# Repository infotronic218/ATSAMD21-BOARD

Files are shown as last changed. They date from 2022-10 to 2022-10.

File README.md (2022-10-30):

# ATSAMD21-BOARD  designed Within Kicad 6
The aim of this project is to design a simple development board for ARM Based MCU line of Microchip for quick use and experimentation of the MCU interfaces. Severals sensors and modules are connected to the MCU interfaces for quick code implementation and testing.
## Used main components in the design 
+ Microchip MCU  ATSAMD21G17D-A
+ UART/USB Transceiver for debugging
+ SW Debug interface over JLINK
+ Bluetooth module (DA14531MOD) over UART 
+ LORA Module (RFM95W) over SPI
+ LED Driver (IS31FL3737) over I2C
+ Lion Battery charger (MCP73831-2-OT)
+ FLASH Memory (16Mbits) Over SPI
+ Temperature and humidity sensor (SHT40) over I2C
+ Digital LED (IN-PI554FCH)
+ GPIO exposed pins 
## PCB LAYOUT VIEWS 
 
1. TOP LAYER LAYOUT 

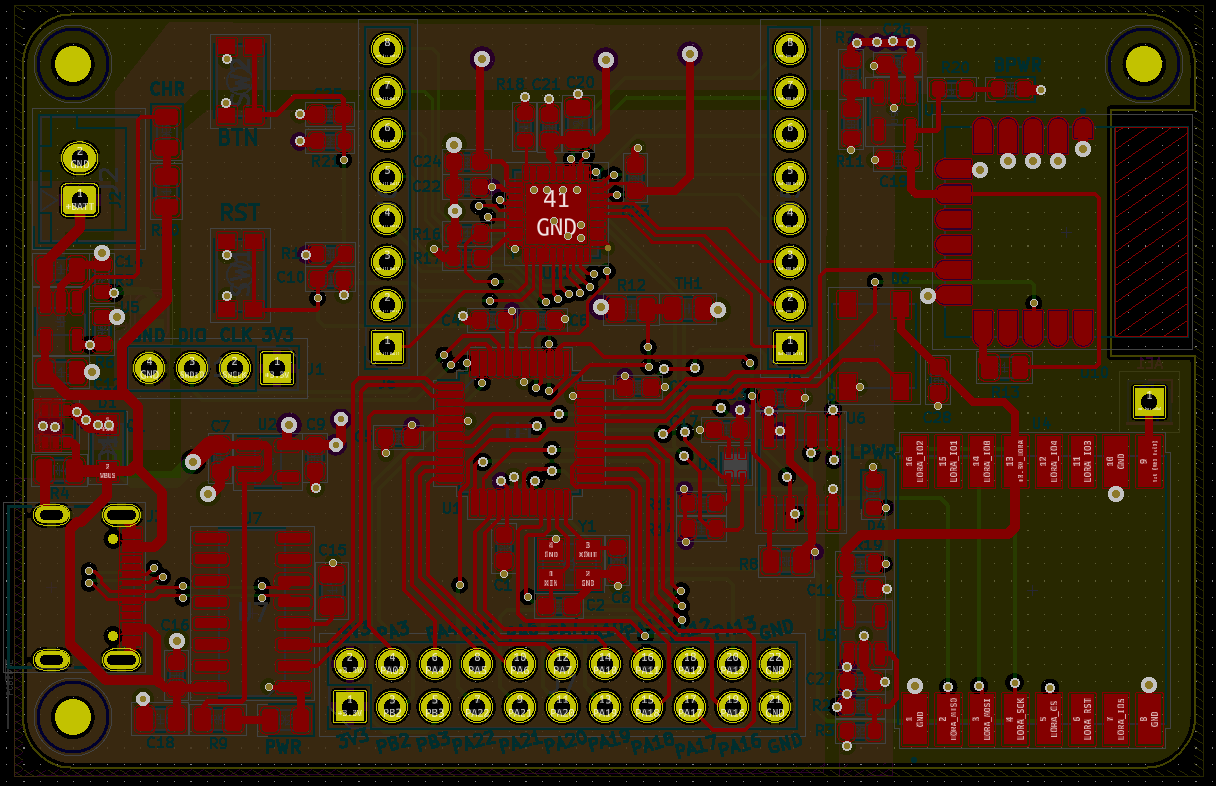
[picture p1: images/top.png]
Top layer


2. BOTTOM LAYER LAYOUT

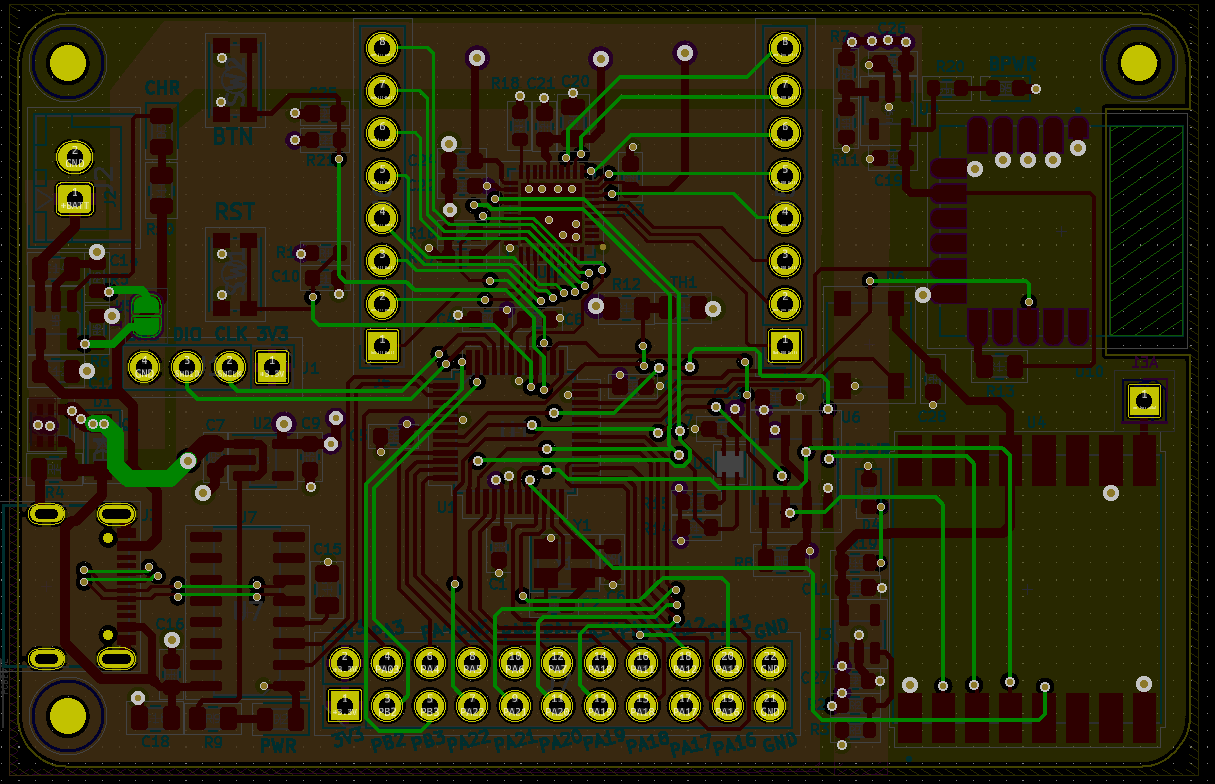
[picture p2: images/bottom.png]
Bottom layer


3. 3D VIEW

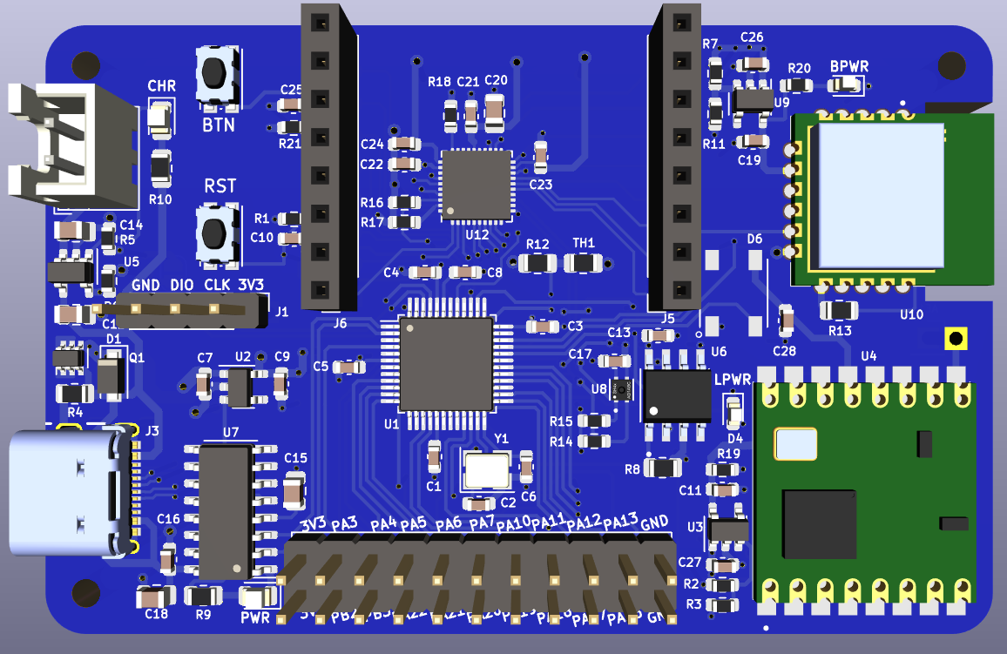
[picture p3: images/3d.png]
3D View


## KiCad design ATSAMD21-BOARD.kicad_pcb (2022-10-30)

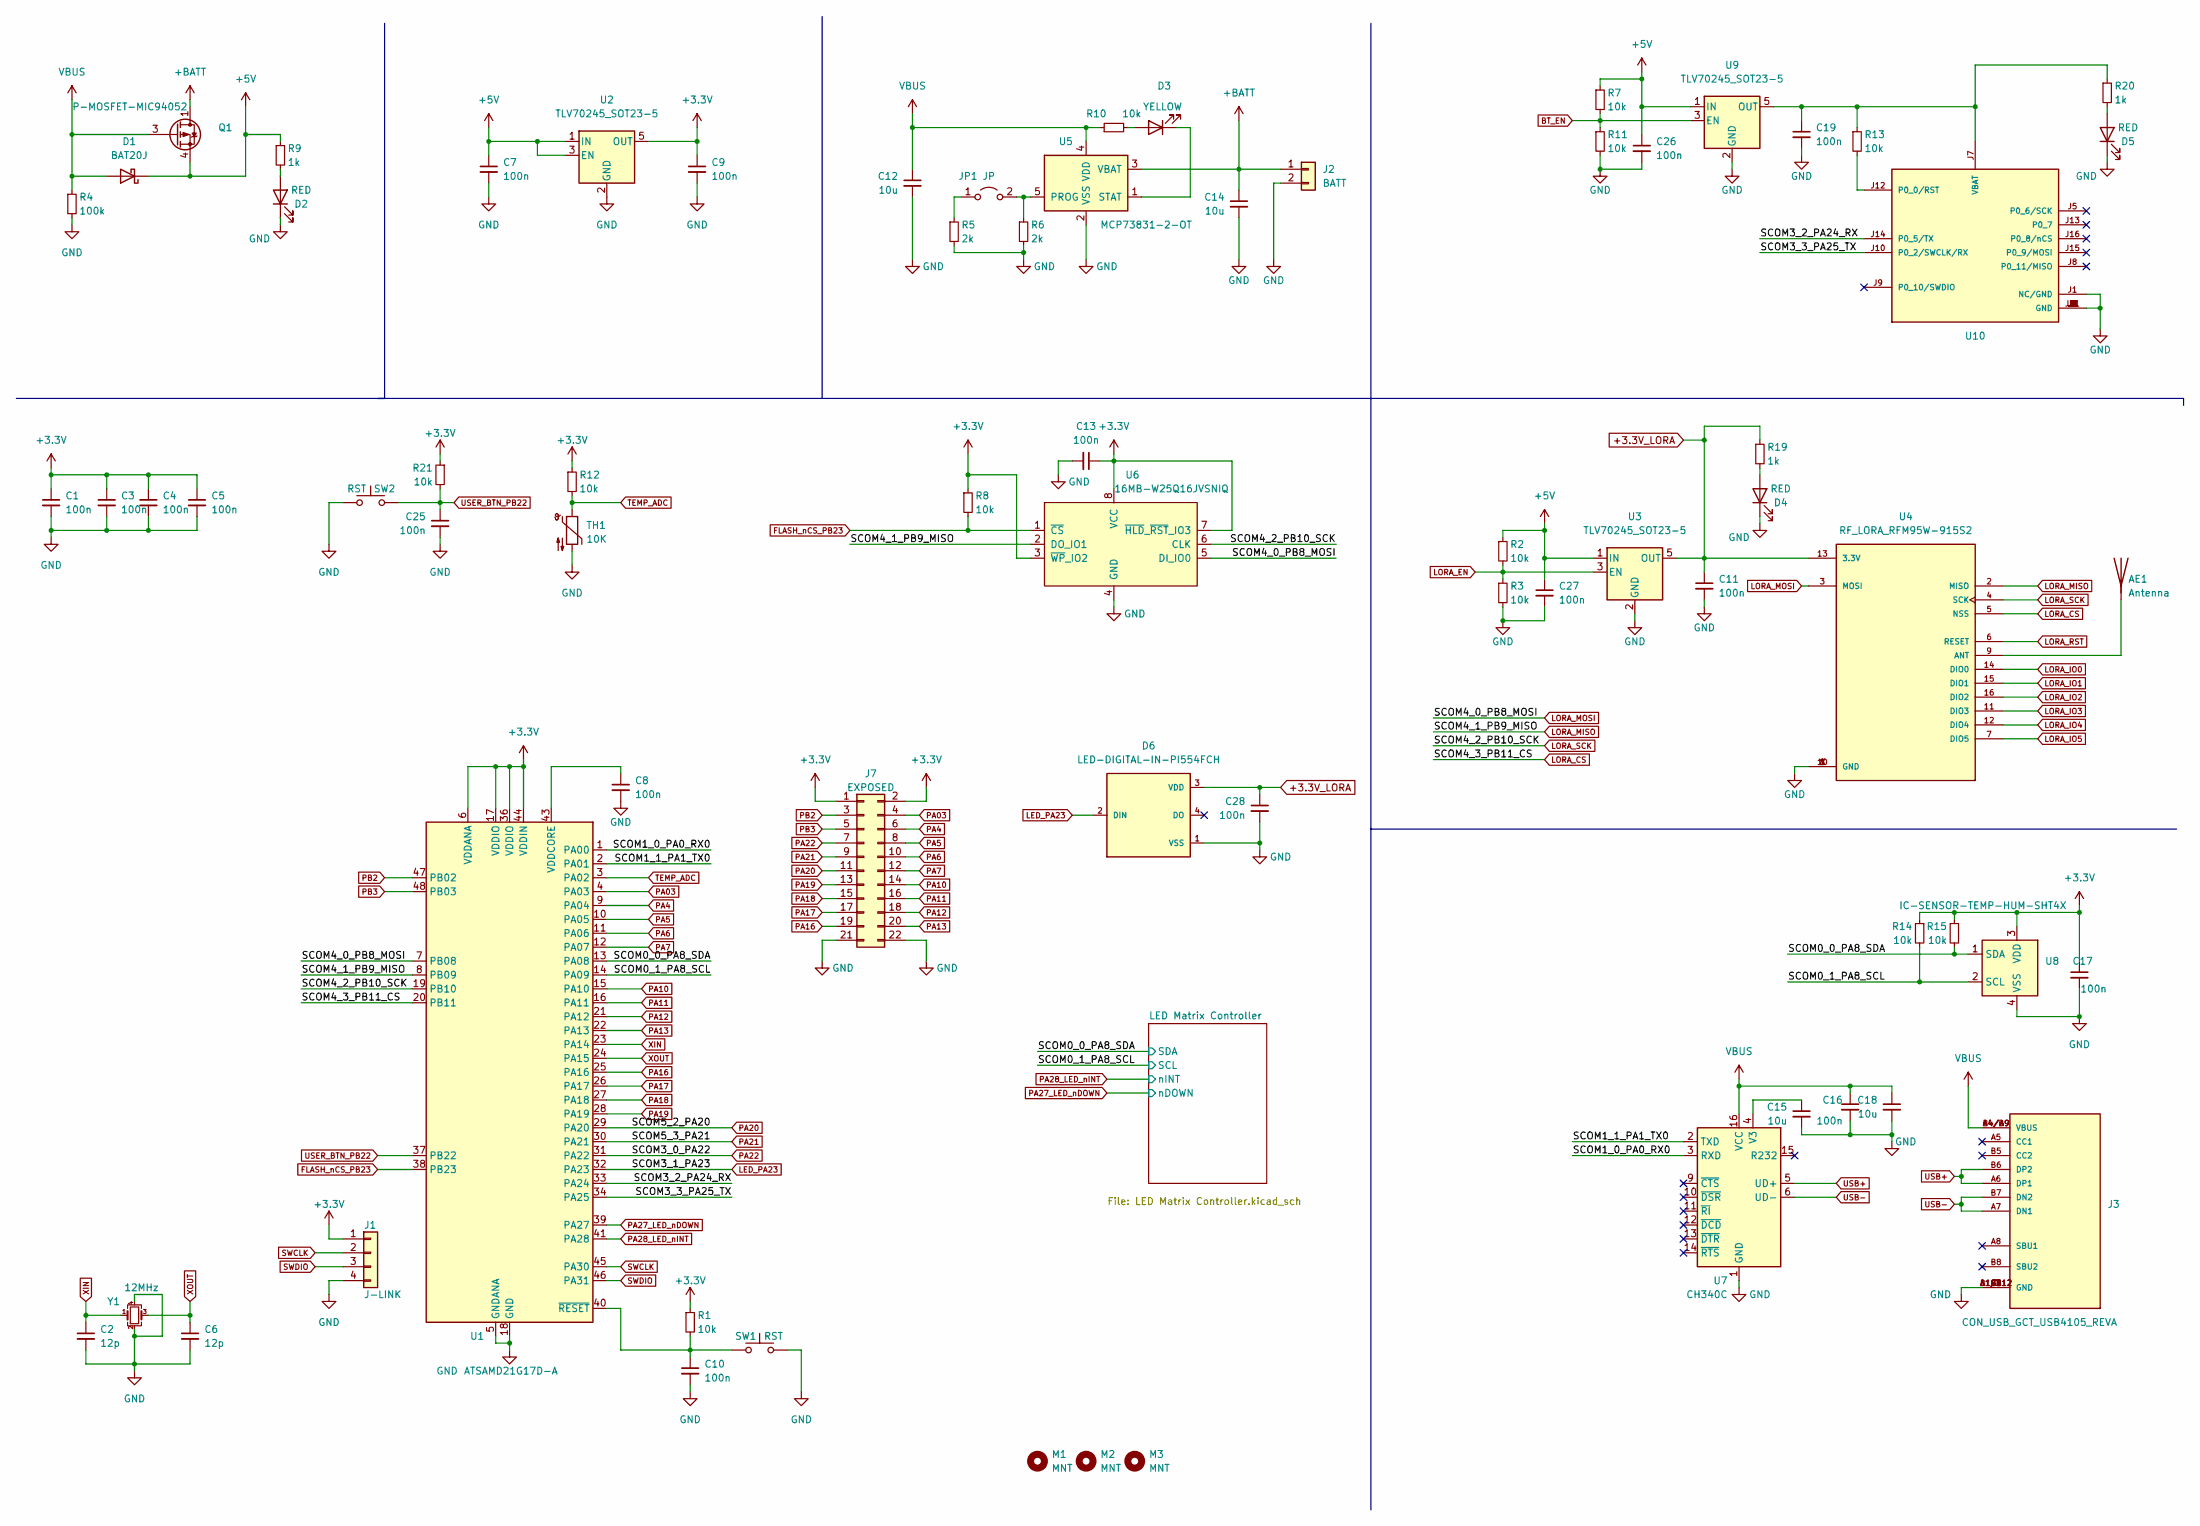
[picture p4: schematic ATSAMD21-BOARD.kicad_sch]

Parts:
AE1: Antenna; CON_ANTENNA_1PIN
C1, C3, C4, C5, C7, C8, C9, C10, C11, C13, C16, C17, C19, C25, C26, C27, C28: 100n; C_0603_1608Metric
C2, C6: 12p; C_0603_1608Metric
C12, C14, C15, C18: 10u; C_0805_2012Metric
D1: BAT20J; D_SOD-123F
D2: RED; LED_0805_2012Metric
D3: YELLOW; LED_0805_2012Metric
D4, D5: RED; LED_0603_1608Metric
D6: LED-DIGITAL-IN-PI554FCH
J1: J-LINK; PinHeader_1x04_P2.54mm_Vertical
J2: BATT; JST_XH_B2B-XH-A_1x02_P2.50mm_Vertical
J3: CON_USB_GCT_USB4105_REVA; PARTREV 0.2
J7: EXPOSED; PinHeader_2x11_P2.54mm_Vertical
JP1: JP; SolderJumper-2_P1.3mm_Open_RoundedPad1.0x1.5mm
M1, M2, M3: MNT; MountingHole_2.1mm
Q1: P-MOSFET-MIC94052; SOT-363_SC-70-6
R1, R2, R3, R7, R11, R14, R15, R21: 10k; R_0603_1608Metric
R4: 100k; R_0805_2012Metric
R5, R6: 2k; R_0603_1608Metric
R8, R10, R12, R13: 10k; R_0805_2012Metric
R9: 1k; R_0805_2012Metric
R19, R20: 1k; R_0603_1608Metric
SW1, SW2: RST; SW_Push_1P1T_NO_CK_KMR2
TH1: 10K; R_0805_2012Metric
U1: ATSAMD21G17D-A; TQFP-48_7x7mm_P0.5mm
U2, U3, U9: TLV70245_SOT23-5; SOT-23-5
U4: RF_LORA_RFM95W-915S2
U5: MCP73831-2-OT; SOT-23-5
U6: 16MB-W25Q16JVSNIQ; IC-FLASH-16MB-W25Q16JVSNIQ; MPN W25Q16JVSNIQ; Mouser 454-W25Q16JVSNIQ
U7: CH340C; SOIC-16_3.9x9.9mm_P1.27mm
U8: IC-SENSOR-TEMP-HUM-SHT4X; MPN SHT40-AD1B-R3; Mouser 403-SHT40-AD1B-R3
U10: DA14531MOD-00F01002
Y1: 12MHz; Crystal_SMD_3225-4Pin_3.2x2.5mm

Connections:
+3.3V: C1.1, C3.1, C4.1, C5.1, C9.1, C13.1, C17.1, J1.1, J7.1, J7.2, R1.1, R8.1, R12.1, R14.1, R15.1, R21.1, U1.6 (VDDANA), U1.17 (VDDIO), U1.36 (VDDIO), U1.44 (VDDIN), U2.5 (OUT), U6.3 (~WP_IO2), U6.7 (~HLD_~RST_IO3), U6.8 (VCC), U8.3 (VDD); also elsewhere on the board
+3.3V_LORA: C11.1, C28.1, D6.3 (VDD), R19.1, U3.5 (OUT), U4.13 (3.3V)
+5V: C7.1, C26.1, C27.1, D1.1 (K), Q1.4 (S), R2.1, R7.1, R9.1, U2.1 (IN), U2.3 (EN), U3.1 (IN), U9.1 (IN); also elsewhere on the board
+BATT: C14.1, J2.1, Q1.1 (D), Q1.2 (S), Q1.5 (D), Q1.6 (D), U5.3 (VBAT)
/SCOM0_0_PA8_SDA: R15.2, U1.13 (PA08), U8.1 (SDA); also elsewhere on the board
/SCOM0_1_PA8_SCL: R14.2, U1.14 (PA09), U8.2 (SCL); also elsewhere on the board
/SCOM1_0_PA0_RX0: U1.1 (PA00), U7.3 (RXD)
/SCOM1_1_PA1_TX0: U1.2 (PA01), U7.2 (TXD)
/SCOM3_2_PA24_RX: U1.33 (PA24), U10.J14 (P0_5/TX)
/SCOM3_3_PA25_TX: U1.34 (PA25), U10.J10 (P0_2/SWCLK/RX)
BT_EN: R7.2, R11.1, U9.3 (EN)
FLASH_nCS_PB23: R8.2, U1.38 (PB23), U6.1 (~CS)
GND: C1.2, C2.2, C3.2, C4.2, C5.2, C6.2, C7.2, C8.2, C9.2, C10.2, C11.2, C12.2, C13.2, C14.2, C15.2, C16.2, C17.2, C18.2, C19.2, C25.2, C26.2, C27.2, C28.2, D2.1 (K), D4.1 (K), D5.1 (K), D6.1 (VSS), J1.4, J2.2, J3.A1/B12 (GND), J3.B1/A12 (GND), J3.G1 (GND), J3.G2 (GND), J3.G3 (GND), J3.G4 (GND), J7.21, J7.22, R3.2, R4.2, R5.2, R6.2, R11.2, SW1.2, SW2.2, TH1.2, U1.5 (GNDANA), U1.18 (GND), U1.35 (GND), U1.42 (GND), U2.2 (GND), U3.2 (GND), U4.1 (GND), U4.8 (GND), U4.10 (GND), U5.2 (VSS), U6.4 (GND), U7.1 (GND), U8.4 (VSS), U9.2 (GND), U10.J1 (NC/GND), U10.J2 (GND), U10.J3 (GND), U10.J4 (GND), U10.J6 (GND), U10.J11 (GND), Y1.2, Y1.4; also elsewhere on the board
LED_PA23: D6.2 (DIN), U1.32 (PA23)
LORA_CS: U1.20 (PB11), U4.5 (NSS)
LORA_EN: R2.2, R3.1, U3.3 (EN)
LORA_IO0: U4.14 (DIO0)
LORA_IO1: U4.15 (DIO1)
LORA_IO2: U4.16 (DIO2)
LORA_IO3: U4.11 (DIO3)
LORA_IO4: U4.12 (DIO4)
LORA_IO5: U4.7 (DIO5)
LORA_MISO: U1.8 (PB09), U4.2 (MISO), U6.2 (DO_IO1)
LORA_MOSI: U1.7 (PB08), U4.3 (MOSI), U6.5 (DI_IO0)
LORA_RST: U4.6 (RESET)
LORA_SCK: U1.19 (PB10), U4.4 (SCK), U6.6 (CLK)
unnamed: AE1.1 (A), U4.9 (ANT)
unnamed: C8.1, U1.43 (VDDCORE)
unnamed: C10.1, R1.2, SW1.1, U1.40 (~RESET)
unnamed: C15.1, U7.4 (V3)
unnamed: C19.1, R13.1, R20.1, U9.5 (OUT), U10.J7 (VBAT)
unnamed: D2.2 (A), R9.2
unnamed: D3.1 (K), U5.1 (STAT)
unnamed: D3.2 (A), R10.2
unnamed: D4.2 (A), R19.2
unnamed: D5.2 (A), R20.2
unnamed: JP1.1 (A), R5.1
unnamed: JP1.2 (B), R6.1, U5.5 (PROG)
unnamed: R13.2, U10.J12 (P0_0/RST)
PA03: J7.4, U1.4 (PA03)
PA4: J7.6, U1.9 (PA04)
PA5: J7.8, U1.10 (PA05)
PA6: J7.10, U1.11 (PA06)
PA7: J7.12, U1.12 (PA07)
PA10: J7.14, U1.15 (PA10)
PA11: J7.16, U1.16 (PA11)
PA12: J7.18, U1.21 (PA12)
PA13: J7.20, U1.22 (PA13)
PA16: J7.19, U1.25 (PA16)
PA17: J7.17, U1.26 (PA17)
PA18: J7.15, U1.27 (PA18)
PA19: J7.13, U1.28 (PA19)
PA20: J7.11, U1.29 (PA20)
PA21: J7.9, U1.30 (PA21)
PA22: J7.7, U1.31 (PA22)
PA27_LED_nDOWN: U1.39 (PA27); also elsewhere on the board
PA28_LED_nINT: U1.41 (PA28); also elsewhere on the board
PB2: J7.3, U1.47 (PB02)
PB3: J7.5, U1.48 (PB03)
SWCLK: J1.2, U1.45 (PA30)
SWDIO: J1.3, U1.46 (PA31)
TEMP_ADC: R12.2, TH1.1, U1.3 (PA02)
USB+: J3.A6 (DP1), J3.B6 (DP2), U7.5 (UD+)
USB-: J3.A7 (DN1), J3.B7 (DN2), U7.6 (UD-)
USER_BTN_PB22: C25.1, R21.2, SW2.1, U1.37 (PB22)
VBUS: C12.1, C16.1, C18.1, D1.2 (A), J3.A4/B9 (VBUS), J3.B4/A9 (VBUS), Q1.3 (G), R4.1, R10.1, U5.4 (VDD), U7.16 (VCC)
XIN: C2.1, U1.23 (PA14), Y1.1
XOUT: C6.1, U1.24 (PA15), Y1.3

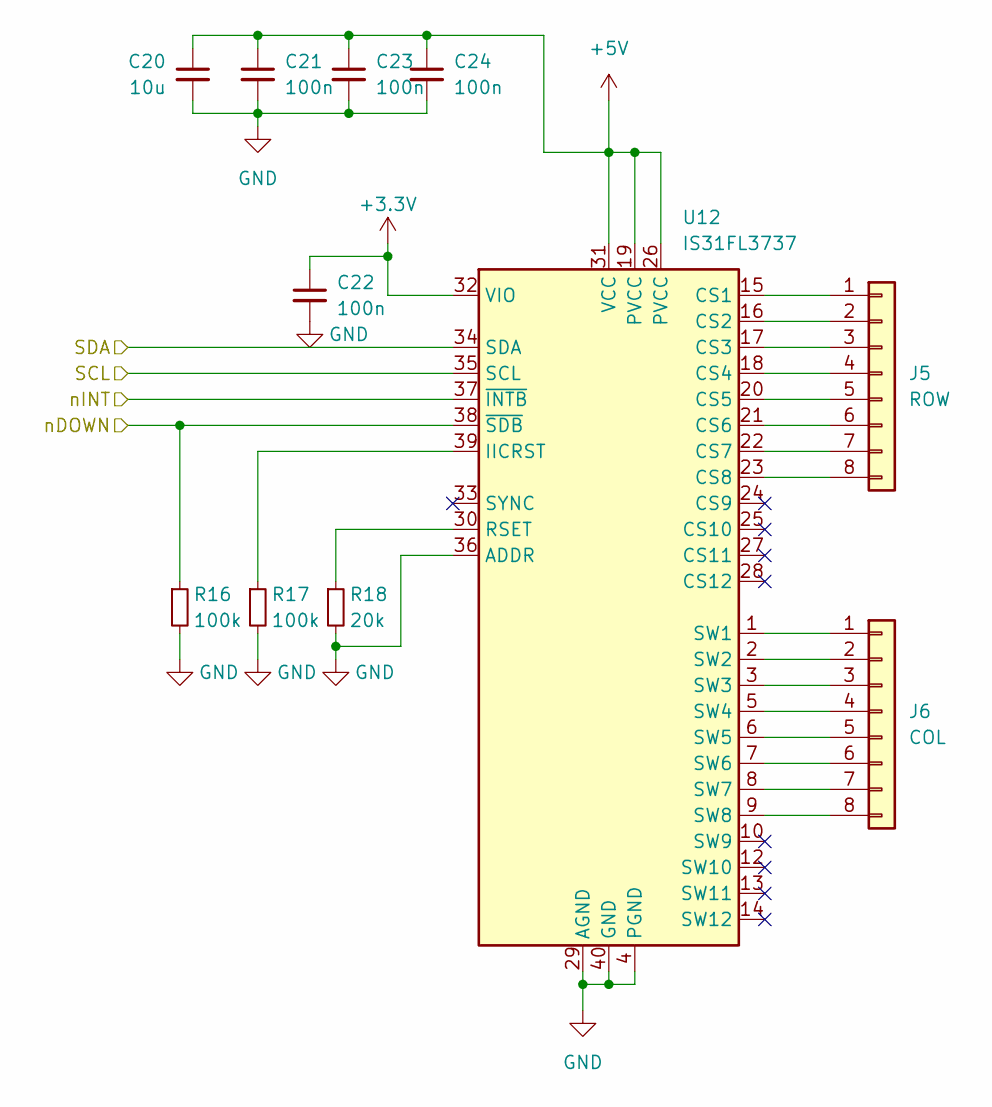
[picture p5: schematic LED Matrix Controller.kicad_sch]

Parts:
C20: 10u; C_0805_2012Metric
C21, C22, C23, C24: 100n; C_0603_1608Metric
J5: ROW; PinSocket_1x08_P2.54mm_Vertical
J6: COL; PinSocket_1x08_P2.54mm_Vertical
R16, R17: 100k; R_0603_1608Metric
R18: 20k; R_0603_1608Metric
U12: IS31FL3737; QFN-40-1EP_5x5mm_P0.4mm_EP3.6x3.6mm

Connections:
+3.3V: C22.1, U12.32 (VIO); also elsewhere on the board
+5V: C20.1, C21.1, C23.1, C24.1, U12.19 (PVCC), U12.26 (PVCC), U12.31 (VCC); also elsewhere on the board
/SCOM0_0_PA8_SDA: U12.34 (SDA); also elsewhere on the board
/SCOM0_1_PA8_SCL: U12.35 (SCL); also elsewhere on the board
GND: C20.2, C21.2, C22.2, C23.2, C24.2, R16.2, R17.2, R18.2, U12.4 (PGND), U12.11 (PGND), U12.29 (AGND), U12.36 (ADDR), U12.40 (GND), U12.41 (GND); also elsewhere on the board
unnamed: J5.1, U12.15 (CS1)
unnamed: J5.2, U12.16 (CS2)
unnamed: J5.3, U12.17 (CS3)
unnamed: J5.4, U12.18 (CS4)
unnamed: J5.5, U12.20 (CS5)
unnamed: J5.6, U12.21 (CS6)
unnamed: J5.7, U12.22 (CS7)
unnamed: J5.8, U12.23 (CS8)
unnamed: J6.1, U12.1 (SW1)
unnamed: J6.2, U12.2 (SW2)
unnamed: J6.3, U12.3 (SW3)
unnamed: J6.4, U12.5 (SW4)
unnamed: J6.5, U12.6 (SW5)
unnamed: J6.6, U12.7 (SW6)
unnamed: J6.7, U12.8 (SW7)
unnamed: J6.8, U12.9 (SW8)
unnamed: R17.1, U12.39 (IICRST)
unnamed: R18.1, U12.30 (RSET)
PA27_LED_nDOWN: R16.1, U12.38 (~SDB); also elsewhere on the board
PA28_LED_nINT: U12.37 (~INTB); also elsewhere on the board

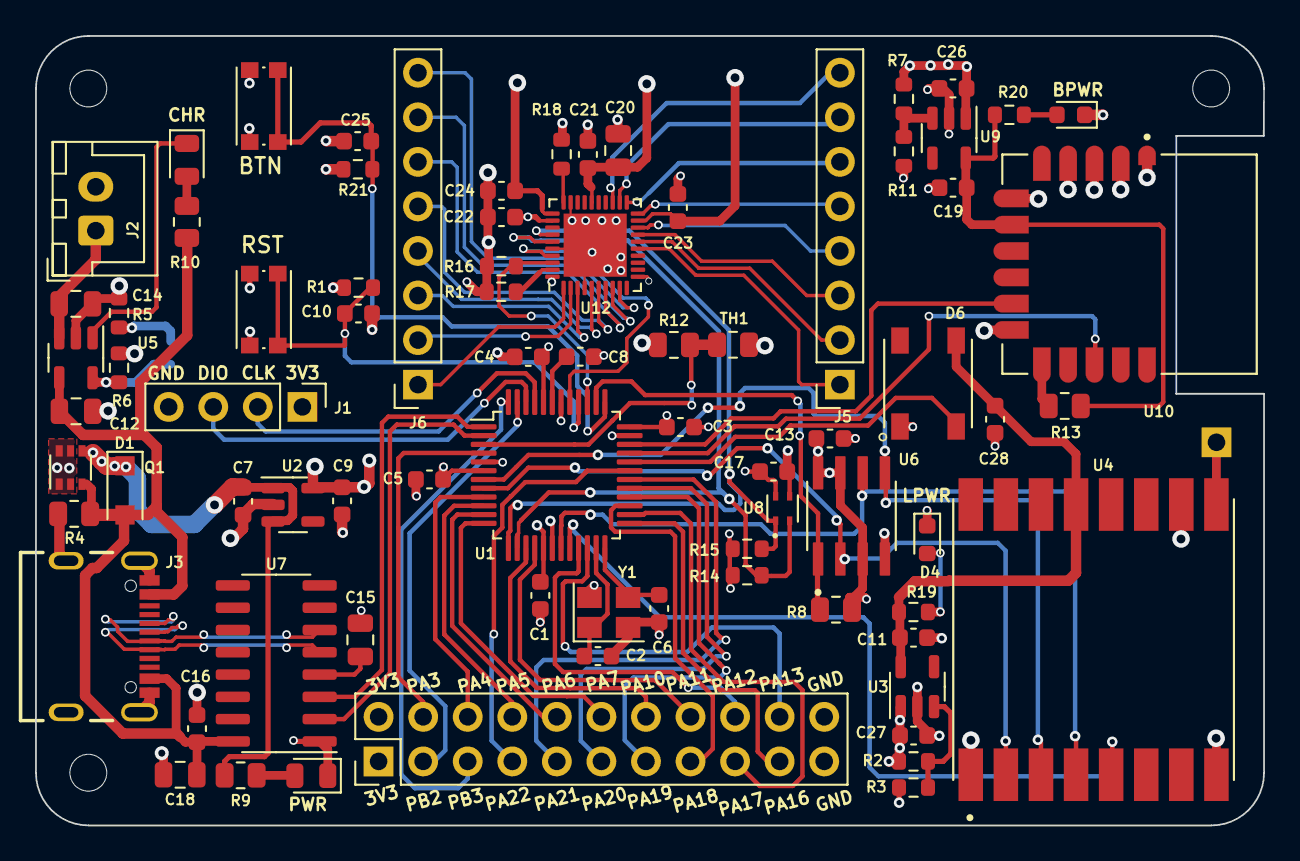
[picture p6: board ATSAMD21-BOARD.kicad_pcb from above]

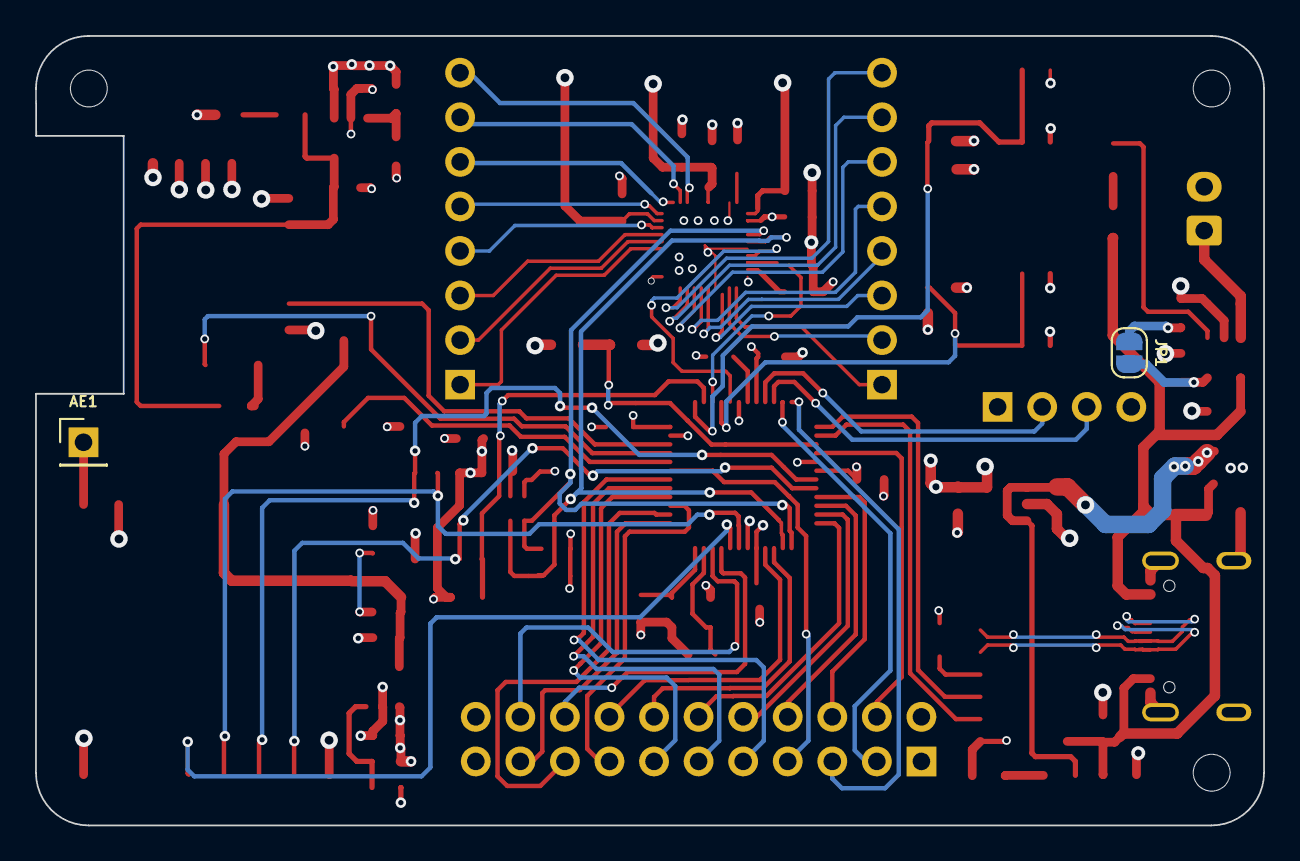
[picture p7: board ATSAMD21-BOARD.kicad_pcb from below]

Board: 4 copper layers, 70.0 x 45.0 mm, 82 parts (2 on the bottom side), 79 nets.

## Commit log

2022-10-23 First commit of the design
    [ATSAMD21-BOARD.kicad_pcb, ATSAMD21-BOARD.kicad_sch, LED Matrix Controller.kicad_sch]
2022-10-23 Update the design
    [ATSAMD21-BOARD.kicad_pcb]
2022-10-23 Update the board design
    [ATSAMD21-BOARD.kicad_pcb]
2022-10-30 Update the board description
    [ATSAMD21-BOARD.kicad_sch]
2022-10-30 Update the board
